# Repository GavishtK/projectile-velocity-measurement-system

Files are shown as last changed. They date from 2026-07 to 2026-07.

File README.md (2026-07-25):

# Projectile Velocity Measurement System (PVMS)

> **Development of an IoT-Based Projectile Velocity Measurement System**







---

# 📖 Overview

The **Projectile Velocity Measurement System (PVMS)** is an embedded system designed to accurately measure projectile velocity using the **Optical Time-of-Flight (ToF)** principle.

The system employs two optical sensing gates connected to an **ESP32** microcontroller. As a projectile passes through the sensing gates, the ESP32 records the elapsed time with microsecond precision and calculates the projectile's velocity.

The measured velocity is displayed in real time on an OLED display and simultaneously transmitted through the Serial Monitor for debugging and data logging.

To improve hardware integration and reliability, a **custom PCB was designed using KiCad**, incorporating interfaces for the ESP32, OLED display, optical sensors, laser modules, and power connections.

This project was developed as part of a **summer internship at DRDO**. This repository contains only my original implementation, documentation, and hardware design intended for educational and portfolio purposes. No confidential or restricted information has been included.

---

# 📷 Project Preview

## Hardware Prototype

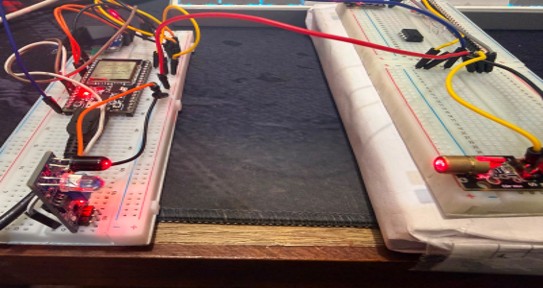
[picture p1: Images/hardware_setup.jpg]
Hardware Setup


## OLED Display

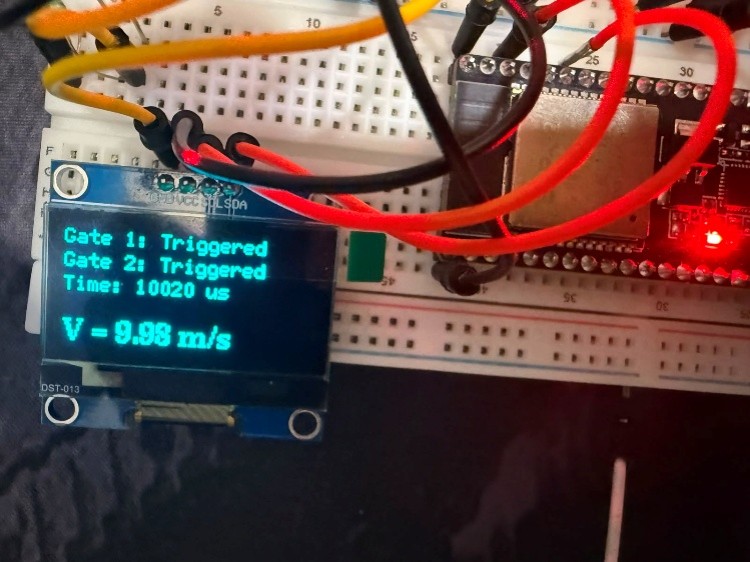
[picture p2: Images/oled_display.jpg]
OLED Display


## PCB Schematic

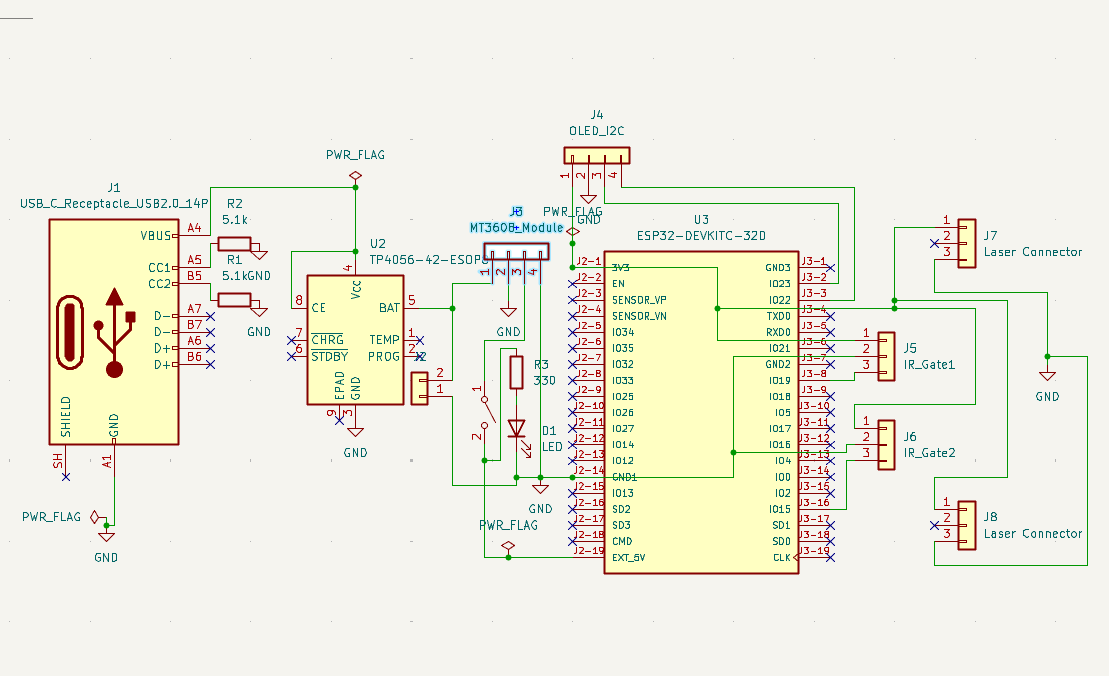
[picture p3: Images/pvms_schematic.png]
PCB Schematic


## PCB Layout

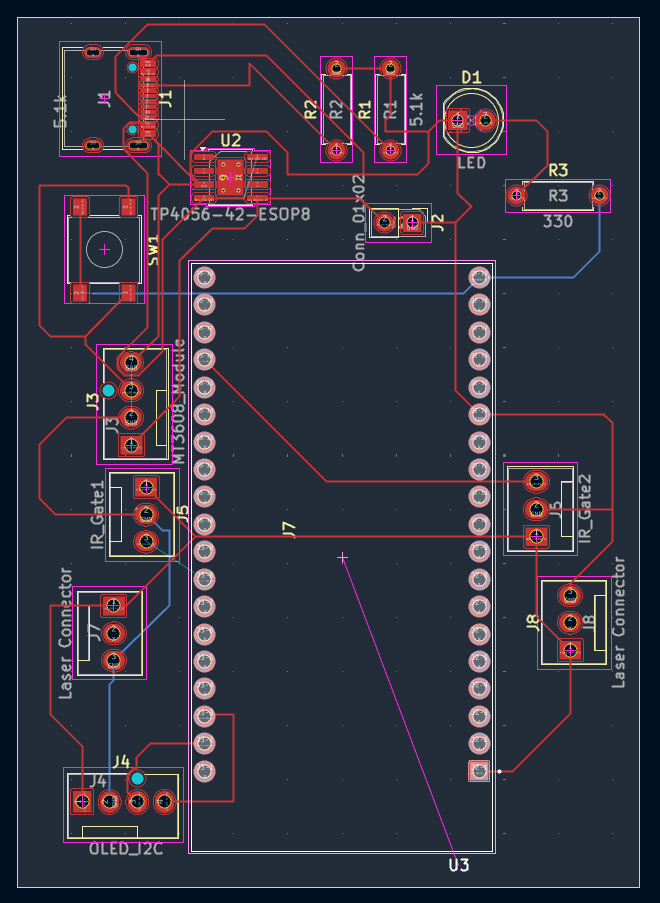
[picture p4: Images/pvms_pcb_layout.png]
PCB Layout


## PCB 3D Model

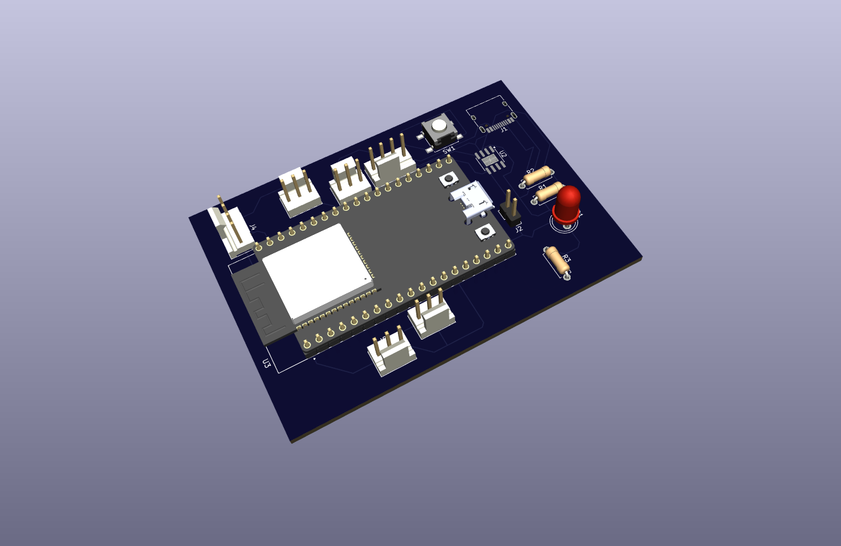
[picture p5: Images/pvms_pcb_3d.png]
PCB 3D Model


---

# ✨ Features

- High-speed projectile velocity measurement
- Optical Time-of-Flight sensing
- ESP32-based embedded system
- Microsecond precision using hardware interrupts
- Real-time OLED display
- Serial Monitor output
- Automatic timeout handling
- Low-cost implementation
- Custom KiCad PCB
- Compact and portable design

---

# ⚙ Hardware Used

| Component | Quantity |
|---|---|
| ESP32 DevKit V1 | 1 |
| SSD1306 OLED Display (128×64) | 1 |
| Laser Modules | 2 |
| Photodiodes | 2 |
| Breadboard | 1 |
| Jumper Wires | As Required |
| USB Power Supply | 1 |

---

# 🛠 Software Used

- Arduino IDE
- ESP32 Board Package
- KiCad
- Adafruit SSD1306 Library
- Adafruit GFX Library
- Wire Library

---

# 💻 PCB Design

A custom PCB was designed using **KiCad** to simplify wiring, improve reliability, and provide a compact hardware platform.

### PCB Features

- ESP32 interface
- OLED display connector
- Optical sensor connectors
- Laser module connectors
- Power input connector
- Compact PCB layout
- 3D STEP model included

---

# 🚀 Working Principle

The system consists of two optical sensing gates placed at a fixed distance.

1. The first optical gate detects the projectile.
2. ESP32 starts a high-resolution timer using hardware interrupts.
3. The second optical gate detects the projectile.
4. ESP32 stops the timer.
5. Velocity is calculated using the Time-of-Flight equation.

\[
Velocity = \frac{Distance}{Time}
\]

The calculated velocity is displayed on the OLED screen and transmitted through the Serial Monitor.

---

# 📋 Technical Specifications

| Parameter | Value |
|---|---|
| Controller | ESP32 DevKit V1 |
| Measurement Method | Optical Time-of-Flight |
| Timing Resolution | Microseconds |
| Display | SSD1306 OLED |
| PCB Software | KiCad |
| Firmware | Arduino C++ |

---

# 🧰 Skills Demonstrated

- Embedded Systems
- ESP32 Programming
- Arduino C++
- PCB Design (KiCad)
- Optical Sensor Interfacing
- Hardware Interrupt Programming
- Time-of-Flight Measurement
- Electronic Circuit Design
- Technical Documentation

---

# 📂 Repository Structure

```text
Projectile-Velocity-Measurement-System/
│
├── README.md
├── LICENSE
├── .gitignore
│
├── docs/
│   └── Final_Report.pdf
│
├── src/
│   └── ProjectileVelocityMeasurement.ino
│
├── Images/
│   ├── hardware_setup.jpg
│   ├── oled_display.jpg
│   ├── pvms_schematic.png
│   ├── pvms_pcb_layout.png
│   └── pvms_pcb_3d.png
│
└── pcb/
    ├── pvms.kicad_pro
    ├── pvms.kicad_sch
    ├── pvms.kicad_pcb
    └── pvms.step
```

---

# 📊 Results

The developed prototype successfully measured projectile velocity using optical sensing gates with stable and repeatable measurements.

The system demonstrated:

- Reliable optical triggering
- Accurate microsecond timing
- Stable velocity calculations
- Real-time OLED display
- Successful custom PCB design and 3D model generation

---

# 🔮 Future Improvements

- Rechargeable battery system
- Wireless data logging
- Mobile application
- Cloud connectivity
- 3D-printed enclosure
- Automatic calibration system

---

# 👨‍💻 Author

**Gavisht Karkara**

B.Tech Electronics & Communication Engineering

Thapar Institute of Engineering and Technology

---

# 📜 License

This project is licensed under the MIT License.

---

# ⚠ Disclaimer

This project was developed as part of a summer internship at **DRDO**.

This repository contains only my own implementation, firmware, PCB design, and documentation intended for educational and portfolio purposes. No confidential, proprietary, or restricted information has been included.

## ⭐ If you found this project useful, consider giving it a star!

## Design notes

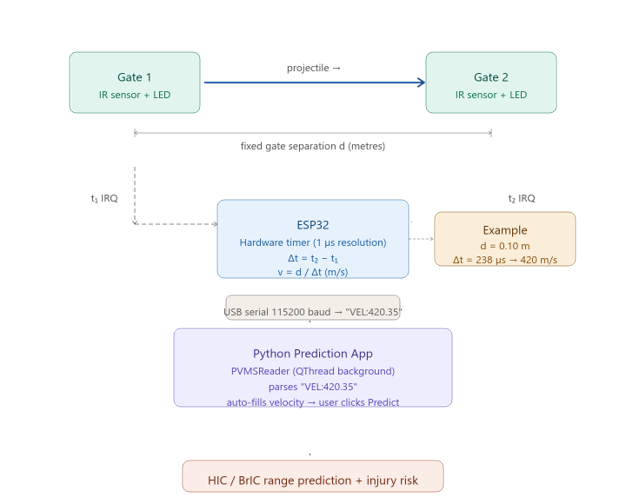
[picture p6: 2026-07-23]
Images/block_diagram.png

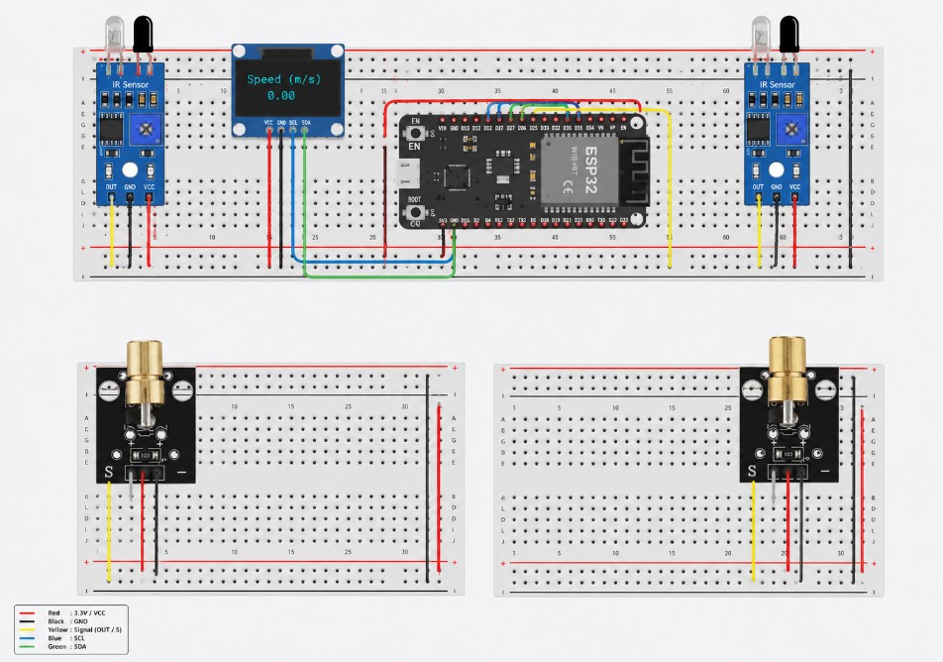
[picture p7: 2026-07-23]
Images/tinkercad.png

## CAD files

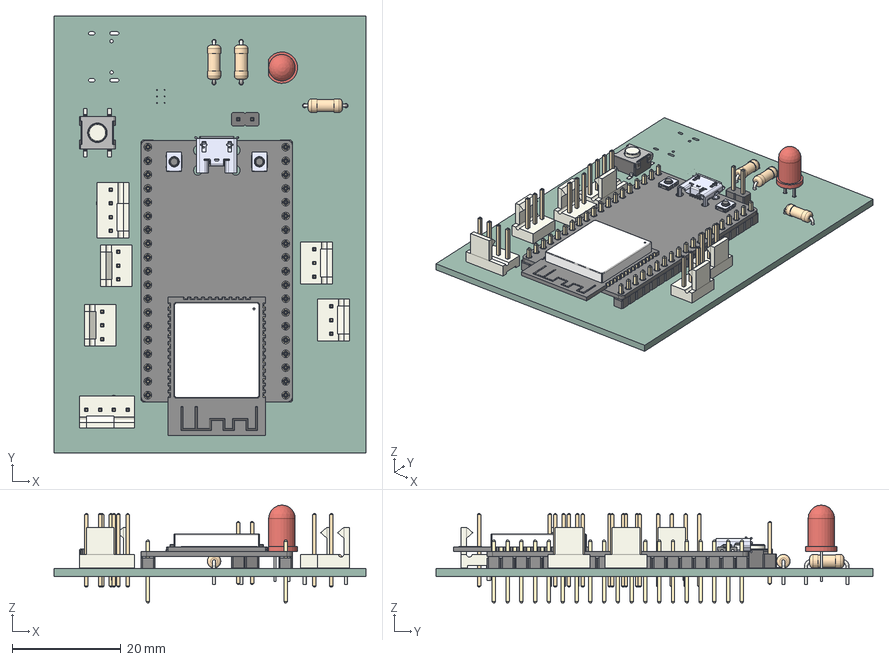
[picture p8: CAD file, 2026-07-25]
pcb/pvms.step
57.5 x 80.5 x 18.0 mm
R_Axial_DIN0207_L63mm_D25mm_P762mm_Horizontal x 3
LED_D5.0mm
SW_SPST_B3S-1000
Fan_Pin_Header_Straight_1x03 x 4
PinHeader_1x02_P254mm_Vertical
Fan_Pin_Header_Straight_1x04 x 2
board
header x 2
ESP32-WROOM-32D
micro usb
button x 2
pvm389E_PCB

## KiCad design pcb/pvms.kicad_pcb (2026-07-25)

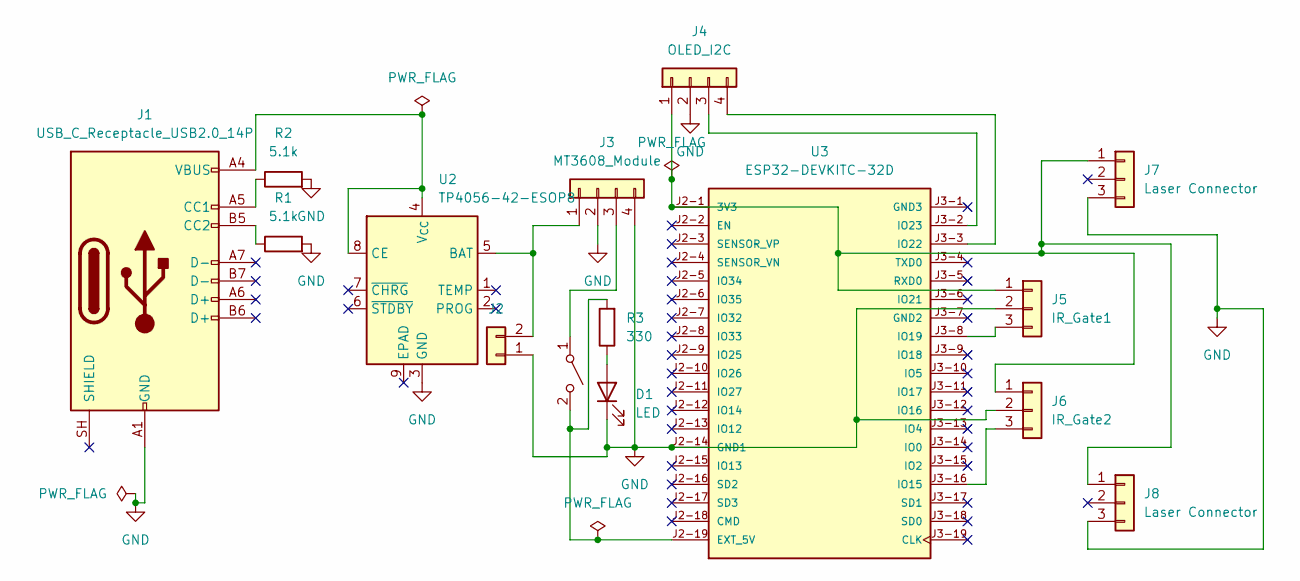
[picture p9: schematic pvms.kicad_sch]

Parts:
D1: LED; LED_D5.0mm
J1: USB_C_Receptacle_USB2.0_14P; USB_C_Receptacle_HRO_TYPE-C-31-M-12
J2: Conn_01x02; PinHeader_1x02_P2.54mm_Vertical
J3: MT3608_Module; FanPinHeader_1x04_P2.54mm_Vertical
J4: OLED_I2C; FanPinHeader_1x04_P2.54mm_Vertical
J5: IR_Gate1; FanPinHeader_1x03_P2.54mm_Vertical
J6: IR_Gate2; FanPinHeader_1x03_P2.54mm_Vertical
J7, J8: Laser Connector; FanPinHeader_1x03_P2.54mm_Vertical
R1, R2: 5.1k; R_Axial_DIN0207_L6.3mm_D2.5mm_P7.62mm_Horizontal
R3: 330; R_Axial_DIN0207_L6.3mm_D2.5mm_P7.62mm_Horizontal
SW1: SW_SPST; SW_SPST_B3S-1000
U2: TP4056-42-ESOP8; SOIC-8-1EP_3.9x4.9mm_P1.27mm_EP2.41x3.3mm_ThermalVias
U3: ESP32-DEVKITC-32D; MODULE_ESP32-DEVKITC-32D; PARTREV V4

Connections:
GND: D1.1 (K), J1.A1 (GND), J1.A12 (GND), J1.B1 (GND), J1.B12 (GND), J2.1, J3.2, J3.4, J4.2, J5.2, J6.2, J7.3, J8.3, R1.2, R2.2, U2.3 (GND), U3.J2-14 (GND1)
unnamed: D1.2 (A), R3.1
unnamed: J1.A5 (CC1), R2.1
unnamed: J1.B5 (CC2), R1.1
unnamed: J2.2, J3.1, U2.5 (BAT)
unnamed: J3.3, SW1.1 (A)
unnamed: J4.1, J5.1, J6.1, J7.1, J8.1, U3.J2-1 (3V3)
unnamed: J4.3, U3.J3-2 (IO23)
unnamed: J4.4, U3.J3-3 (IO22)
unnamed: J5.3, U3.J3-8 (IO19)
unnamed: J6.3, U3.J3-16 (IO15)
unnamed: R3.2, SW1.2 (B), U3.J2-19 (EXT_5V)
unnamed: J1.A4 (VBUS), J1.A9 (VBUS), J1.B4 (VBUS), J1.B9 (VBUS), U2.4 (V_{CC}), U2.8 (CE)

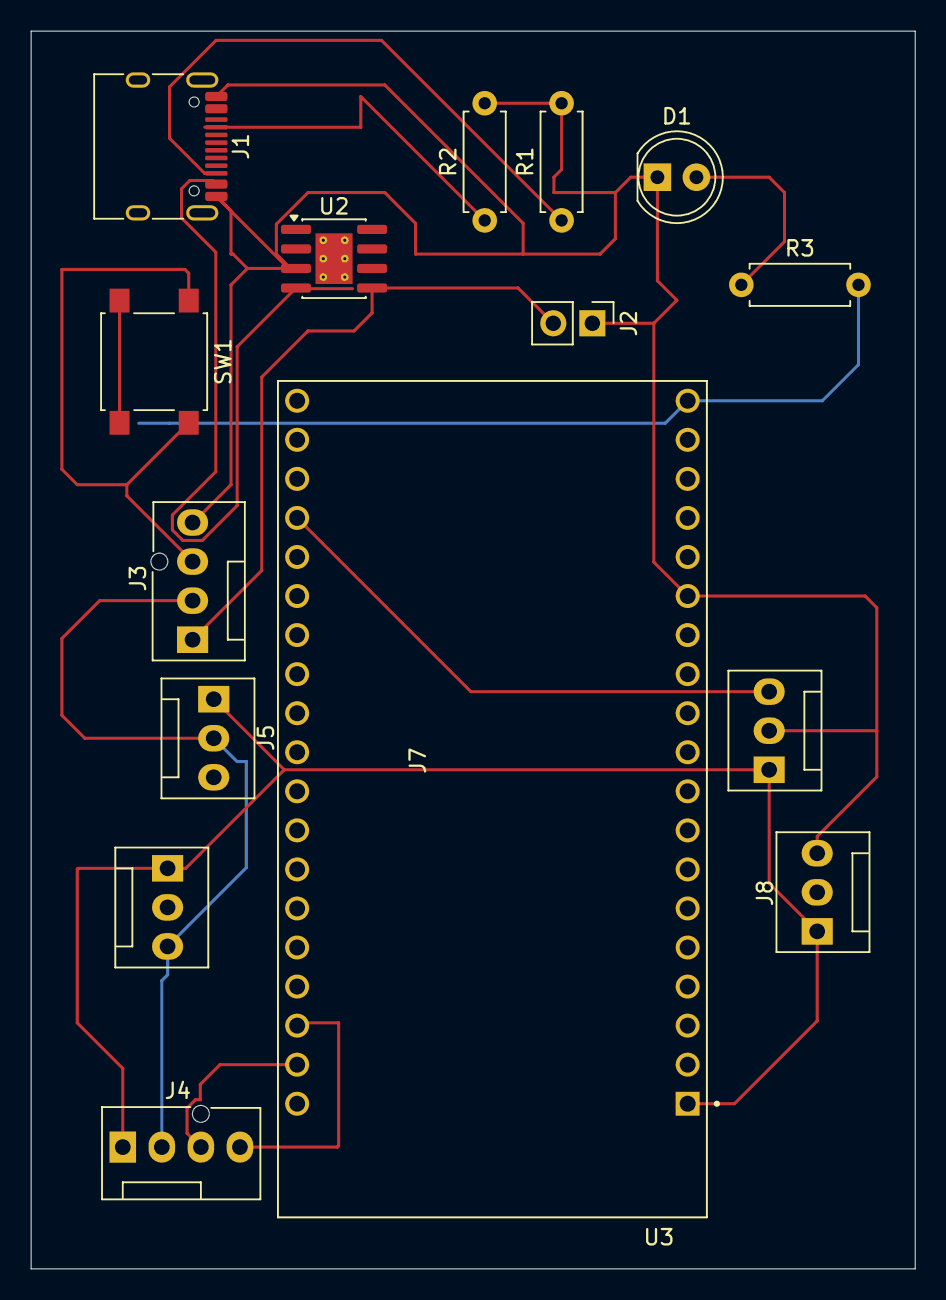
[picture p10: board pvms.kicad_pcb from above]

Board: 2 copper layers, 57.5 x 80.5 mm, 15 parts (0 on the bottom side), 13 nets.

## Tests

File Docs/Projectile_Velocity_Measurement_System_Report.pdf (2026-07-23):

## Abstract

The ballistics helmet test produces massive amounts of sensor data which needs to be analyzed in order to

assess biomechanical injury metrics including HIC36 and BrIC. However, the conventional method of analysis

via the use of commercial software such as NI DIAdem is slow, expensive in terms of licensing fees, and lacks

predictive ability.

The current project entails the development of a desktop application using the Python language for automating

the biomechanical analysis process. The desktop application is developed using the PytS framework and it

imports CSV and Excel files with sensor data (raw or filtered, computes the HIC36 and BrIC, finds the peak

value of all twelve sensor channels, and shows the results in seven pairs of graphs. Another aspect of the

current project included research into the Hybrid III head-neck assembly with the sensors installed on it.

In order to enhance the accuracy of the results generated by the Python software package, the generated results

were compared against NI DIAdem with regard to the data acquired from nine ballistic tests. The corrections

were made in the following manner, with a factor of 1.40 for HIC and 0.57 for BrIC being derived.

The software also incorporates a machine learning model for prediction that includes algorithms such as

random forest, linear regression, and gradient boosting in order to predict the HIC and BrIC with respect to

the speed of the projectile, projectile type, helmet type, and side of impact.

Other features included in the program are a graphical impact side selector, velocity versus drop height map,

and injury severities.

In addition, a compact Prototype of a Projectile Velocity Measurement System (PVMS) was developed using

a breadboard in order to obtain projectile velocities. These velocities were compared to the known reference

values of the velocities obtained from the existing system and the percentage error was computed in order to

test the accuracy of the prototype. The sofiware also contains an impact side selection window, a drop height

to velocity look-up table and injury severity categorization based on biomechanical standards.

The entire system can be summarized to provide an efficient platform for automated biomechanical analysis,

velocity measurements, and injury predictions without expending much manual effort and still agreeing well

with standard reference techniques.

## Table of content

## Chapter 1 - Introduction

### 1.1 Project Background

With the rising need for better personal protection in defense and law enforcement, ballistse helmets have come to be a vital part of protective gear. The key purpose of wearing such helmets is not just protection from penetration by projectiles, but also reduction in the transmission of impact forces to the wearer's head. Even if the projectile is stopped, the force that will be transmitted can be enough to cause TBI

Traumatic Brain Injury (TBI) refers to an injury caused by the action of an external mechanical force on the brain. TBI is divided into two types; that is, penetrating TBI, which involves a foreign body entering the brain, and non-penetrating or blunt TBI, involving rapid movement of the brain within the skull as a result of impact forces. In testing for helmet performance, the non-penetrating TBI is more of a problem since it could happen even if the helmet protects the head from projectile

penetration.

For the purpose of analyzing the efficiency of the ballistic helmet in resisting injuries caused by those mechanisms, a biomechanical test has to be conducted by means of an instrumented head form fitted with calibrated sensors. Data from the tests conducted on impact will be analyzed and injury criteria will be calculated; these criteria will be compared with safety levels.

### 1.2 Problem Definition

The current method of analyzing the collected data regarding the helmet impacts is based mainly on the use of commercially available software programs like NI DIAdem. This process involves manual loading of each individual CSV file, channel selection, filter setting, HIC and BrIC calculation, graph plotting, and writing of all these results down. All this has to be done for each separate test that makes this process quite lengthy and laborious. There is a high risk of errors when dealing with large number of tests performed on helmets using various ammunition types and different points of impact.

A third weakness of the present approach to the analysis is that there is no element of predictability within the system at all. The program only analyzes the results from tests carried out and cannot predict what the values of HIC or BrIC would be under various conditions of the speed of the projectile, the type of ammunition used, the type of helmet used, and the point of contact between the projectile and the helmet. This is especially useful considering the costliness of ballistic testing.

Morcover, the current process is not integrated for the velocity measurement of projectiles in the testing process.The measurement of velocity is always done separately through a commercially available chronograph and the value is then manually input increases the likelihood of data entry errors.

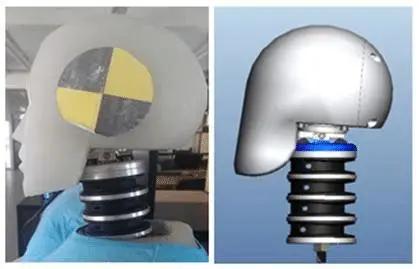
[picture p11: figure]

Figure 1: Head-Neck Assembly

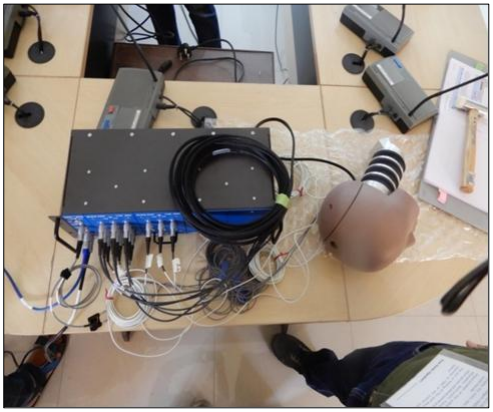
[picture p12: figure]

Figure 2: Head-Neck Assembly Setup

### 1.3 Understanding the Hybrid Ill Head-Neck Assembly

Hybrid III 50th percentile male Anthropomorphic Test Device (ATD) is one of the most commonly employed dummy types for assessment of occupant restraints and protection devices. It was initially designed by General Motors and is presently supported by Humanetics in partnership with SAE International and NHTSA. Hybrid III ATD is listed in the United States Code of Federal Regulations (Part 572, Subpart E), and it is intended to reflect the dimensions of a typical adult male body.

The head module comprises a metal skull made from aluminum and coated with vinyl to mimic the shape of the human head. The neck module has alternating aluminum disks and rubber inserts that mimic the stiffness and damping characteristics of the human neck. This makes it possible for the headform to behave in response to the loads applied in a manner that is comparable to the way the human body behaves, thus allowing the recorded sensor information to be compared against known injury criteria for humans.

The sensors are placed on the head form at points that correspond to the centre of gravity of the human head. The linear accelerometers placed at this point sense acceleration in three mutually perpendicular directions. Angular rate sensors sense rotation around the three mutually perpendicular axes. The neck load cell is a six-axis sensor that measures force and moments transferred across the cervical spine of the human body.

### 1.4 Project Objectives

The main goals of the project include the following:

- Performing research on Hybrid III head-neck subsystem and getting familiar with the sensors employed by the system and their properties, including operating principle, channel number, measurement range, and unit of measurement.
- Creating a desktop application implemented with Python programming language, able to open the raw and filtered CSV/Excel data files, calculate the HIC36 and BrIC indicators, show peak values for all twelve sensor channels, and plot time-history graphs in pairs.
- Checking the differences between HIC and BrIC calculated by Python and NI DIAdem software, determining appropriate correction coefficients, and applying them to improve the accuracy of calculations.
- Implementing a machine learning prediction model which would be able to estimate HIC and BrIC indicators basing on parameters such as projectile velocity, ammunition type, helmet type, and impact side using a database of real experimental data and physics-generated data.
- Creating an intuitive interface that would contain a graphical head diagram for choosing the side of the impact, and a drop height table for easier input of velocities while making drop-test predictions.

## Chapter 2 - Review of Literature

### 2.1 Head Injury Criterion (HIC)

The Head Injury Criterion (HIC) was formulated based on the work by Versace (1971) from the Biomechanics Research Laboratory at Wayne State University. This criterion has been devised based on earlier studies on the tolerance of head trauma, where it was found to have a correlation between the amount and duration of head acceleration and chances of skull fracture. The HIC is currently one of the most accepted biomechanical injury criteria in use today.

HIC combines both the magnitude and duration of head acceleration into a single injury metric, making it a more reliable indicator of head injury risk than peak acceleration alone. The HIC36 criterion used in this project limits the maximum duration of the evaluation window to 36 milliseconds, in accordance with the SAE J211 and FMVSS 208 standards.

HIC is defined as the maximum value of the following expression over all possible time intervals [t₁, t₂]:

HIC = (t2 − t1

)((
1
t2 − t1

) ∫ a(t)dt

(t2

)

t1

)

2.5
( )

where a(t) represents the resultant head acceleration measured in g, while t₁ and t₂ denote the start and end of the selected time interval in seconds.

The exponent 2.5 is based on experimental studies which showed that the severity of head injury depends not only on acceleration but also on the duration for which it acts. As a result, sustained high acceleration produces a much greater injury risk than a short-duration impact. Consequently, even small variations in the acceleration signal can significantly influence the calculated HIC value, highlighting the importance of appropriate signal filtering before analysis.

Algorithm: Sliding Window Maximisation

The HIC value is determined using a brute-force sliding window algorithm applied to the filtered resultant acceleration signal within a ±20 ms interval around the peak acceleration. The computation is performed as follows:

- Select each sample within the impact window as the starting index (i).
- Extend the ending index (j) while ensuring that (t[j] − t[i]) ≤ 36 ms.
- Determine the average acceleration over the selected interval using trapezoidal numerical integration:

### avg =

### ∫ a dt (t₂ − t₁)

- Calculate the HIC value for that interval:

HIC candidate = (t₂ − t₁) × avg².5

- Repeat the process for all possible (i, j) combinations and record the maximum HIC value obtained.

At 50,000 Hz the impact window contains approximately 2,000 samples, making the O(n²) complexity practical for processing an individual test file.

Table 1: HIC Risk Classification

HIC Range | Risk Level | Standard Reference
0 – 250 | Safe | EN 397 drop test safe limit
250 – 1000 | Moderate | NIJ 0106.01 ballistic pass/fail threshold
1000 – 2400 | Severe | FMVSS 208 severe injury region
> 2400 | Critical | FMVSS 208 fatal injury threshold

### 2.2 Brain Injury Criterion (BrIC)

Takhounts et al. (2013) proposed Brain Injury Criterion (BrIC) to address the drawback of HIC, since HIC only accounts for translational acceleration but ignores brain injury due to rotational acceleration. An important mechanism of injury because of rotational acceleration is Diffuse Axonal Injury (DAI). DAI happens when the brain moves rotationally within the skull, stretching and shearing the white matter axons. This injury may lead to unconsciousness, cognitive dysfunction, and, in severe cases, brain injury or even death.

BrIC is defined as:
BrIC = √(
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
where:

- ωx, ωy, ωz are the peak angular velocities about the X (Roll), Y (Pitch), and Z (Yaw) axes, respectively, measured in rad/s.
- WXC, WYC, and WZC represent the critical angular velocity constants corresponding to a 50% probability of AIS 4+ brain injury. These constants were established by Takhounts et al. using reconstructed accident data and finite element head model simulations.
The critical angular velocity constants used are:
- WXC = 66.25 rad/s (Roll – highest tolerance)
- WYC = 56.45 rad/s (Pitch)
- WZC = 42.87 rad/s (Yaw – lowest tolerance and the most critical axis)

Algorithm: Peak Detection on Resultant Time Series

Unlike HIC, BrIC does not require a sliding window. The algorithm is:

- Convert from deg/s to rad/s: ωrad = ωdeg ×

π
180
- Compute BrIC at every sample: BrIC(t) = √(
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
- The peak BrIC is obtained by selecting the maximum BrIC value over the entire duration of the test.

Table 2: BrIC Risk Classification

BrIC Range | Risk Level | Description
0 – 0.20 | Safe | No brain injury expected
0.20 – 0.45 | Low | Minor rotational stress
0.45 – 0.65 | Moderate | Moderate DAI risk
0.65 – 0.80 | Severe | Severe DAI probable
> 0.80 | Critical | Catastrophic brain injury

### 2.3 Helmet Testing Standards

Three standards are relevant to this project:

- NIJ 0106.01 (National Institute of Justice, USA): This is the primary standard used for the certification of ballistic helmets. It specifies that the HIC value must not exceed 1000 during the acceptance testing procedure. Based on the level of protection offered against different ammunition types, helmets are classified into protection levels ranging from Level I to Level IIIA.
- EN 397 (European Standard for Industrial Safety Helmets): This standard applies to the performance evaluation of industrial safety helmets under drop-test conditions. Owing to the comparatively lower impact energies involved, the acceptable HIC limit is 250, which is considerably lower than that specified for ballistic helmet testing.
- IS 4151 (Bureau of Indian Standards): This Indian standard specifies the requirements for protective helmets and serves as the national reference for the procurement and evaluation of helmets used by defence and paramilitary organisations.

### 2.4 Existing Tools and Research Gap

NI DIAdem is one of the most widely used commercial software tools for biomechanical analysis of helmet impact data. It provides built-in functions for calculating HIC and BrIC, configurable signal filtering options, graphical visualization, and automated report generation. Despite these capabilities, the software requires a commercial licence and cannot be readily deployed on systems without a licensed installation. Furthermore, it does not offer any facility for predicting injury metrics before conducting physical impact tests.

Another commonly used platform is MATLAB with the Signal Processing Toolbox, which is extensively employed for signal processing and biomechanical data analysis in research applications. Although MATLAB offers powerful computational and visualization features, its usage is also restricted by licensing requirements.

A review of the available literature indicates that there is no publicly available, licence-free Python-based application that integrates automated biomechanical analysis with machine learning-based injury prediction into a single platform. This identified research gap served as the motivation for developing the system presented in this project, which combines automated signal processing, injury metric computation, and predictive analysis within a unified application.

## Chapter 3 - Sensors and Experimental Setup

### 3.1 Overview of the Head-Neck Assembly

Impact testing of all helmets was performed using a Hybrid III 50th percentile male Anthropometric Test Device (ATD) head-neck assembly. The headform consists of an aluminum skull covered with vinyl skin, closely replicating the geometry and mechanical properties of a human head. The neck is constructed from aluminum and rubber discs designed to mimic human neck flexion and extension. Figure 3 shows the complete Hybrid III head-neck assembly, while Figure 4 illustrates the six-axis neck load cell mounting.

The assembly is equipped with three types of sensors: linear accelerometers, angular rate sensors, and a six-axis neck load cell. Linear accelerometers measure acceleration along three perpendicular axes, angular rate sensors capture rotational motion, and the load cell records forces and moments acting on the neck.

Sensor outputs are recorded using a data acquisition system at a sampling rate of 50,000 samples per second per channel. Each impact test generates a CSV file containing a 22-row metadata header, a time column, and 12 sensor data channels.

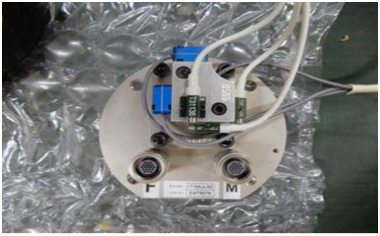
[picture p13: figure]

Figure 3: Load Cell - Six-Axial, Mounted on Headform

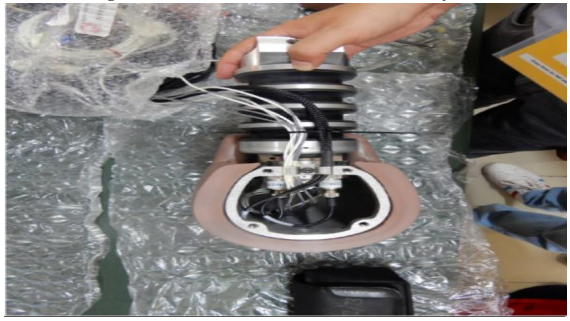
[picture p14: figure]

Figure 4: Load Cell Assembly – Middle View

Figure 4: Head and Neck Assembly - Exploded Views

### 3.2 Linear Acceleration Sensors (Endevco T-Series)

Three piezoresistive accelerometers, which provide measurement of translational acceleration along the X, Y, and Z axes, are installed in the Hybrid III headform. These instruments are attached to the centre of mass of the headform to register the translational acceleration produced during the collision. The working principle of piezoresistive accelerometers is based on the piezoresistive effect in which the seismic mass produces strain in silicon flexure beams with embedded piezoresistors.

The resistance of the piezoresistive sensors changes as a result of the accelerating force acting on the sensor in proportion to the loading force. This change in resistance is measured by a Wheatstone bridge circuit, and as a result, an output voltage is produced which is directly proportional to the acceleration.

Table 3: Linear Accelerometer Channel Assignments

Channel | Sensor ID | Axis | Unit | Range
Chan 0 | T31542 | X (fore-aft) | g | ±2000 g
Chan 1 | T32923 | Y (lateral) | g | ±2000 g
Chan 2 | T31139 | Z (vertical) | g | ±2000 g

Personal Observation
During my study on the sensor layout, I noticed that for successful detection of linear acceleration, it is necessary to arrange each uniaxial accelerometer properly inside the headform.

Table 4: Endevco 7268C Accelerometer Specifications

Parameter | 7268C-2000 (Value)

7268C-500
(Value)

Source

Measurement Range | ±2000 g | ±500 g | Endevco Datasheet 083019
Typical Sensitivity (10V excitation) | 0.20 mV/g (typ) | 0.80 mV/g (typ) | Endevco Datasheet 083019
Minimum Sensitivity | 0.15 mV/g (min) | 0.50 mV/g (min) | Endevco Datasheet 083019
Frequency Response (Z- axis) | 0 – 3,000 Hz (±5%) | 0 – 3,000 Hz (±5%) | Endevco Datasheet 083019

Frequency Response (X,Y
axes)

0 – 1,500 Hz
(±5%)

0 – 1,500 Hz
(±5%)

Endevco Datasheet 083019

Mounted Resonance Freq.
(Z)
26,000 Hz | 17,000 Hz | Endevco Datasheet 083019
Damping Ratio | 0.05 of critical | 0.05 of critical | Endevco Datasheet 083019
Non-linearity + Hysteresis | ±1% FSO | ±1% FSO | Endevco Datasheet 083019
Shock Survival (half-sine) | 10,000 g (200 µs) | 5,000 g (300 µs) | Endevco Datasheet 083019
Transverse Sensitivity | <3% max | <3% max | Endevco Datasheet 083019
Zero Measurand Output | ±100 mV max | ±100 mV max | Endevco Datasheet 083019
Excitation Voltage | 5 or 10 Vdc | 5 or 10 Vdc | Endevco Datasheet 083019
Weight (sensor only) | 8 g | 8 g | Endevco Datasheet 083019
Dimensions | 12.7 × 10.7 × 13.7 mm | 12.7 × 10.7 × 13.7 mm | Endevco PR Release, 2010
Operating Temperature | –18°C to +66°C | –18°C to +66°C | Endevco Datasheet 083019
Calibration Traceability | NIST traceable | NIST traceable | Endevco Datasheet 083019

Datasheet: Endevco 7268C specifications obtained from the official Endevco datasheet.

### 3.3 Angular Rate Sensors (ARS)

Three uniaxial ARSs are used for measuring the angular rotation about the X (roll), Y (pitch), and Z (yaw) axes. The ARSs work based on the Coriolis principle, which states that the vibration component of the sensor experiences a force acting perpendicular to the vibration as well as the rotating axis. This Coriolis force is directly proportional to the angular velocity of the input, thus resulting in an output voltage that is proportional to the rotational speed in deg/s.

The channel assignments, sensor IDs, measurement axes, and output units of the angular rate sensors used during testing are listed in Table 5.

Table 5: Angular Rate Sensor Channel Assignments

Channel | Sensor ID | Axis | Unit
Chan 3 | ARS21556 | X - Roll | deg/s
Chan 4 | ARS15978 | Y - Pitch | deg/s
Chan 5 | ARS21564 | Z - Yaw | deg/s

The orientation of the roll (X), pitch (Y), and yaw (Z) axes with respect to the headform is illustrated in Figure 6. Understanding this axis convention is essential for correctly interpreting the angular velocity measurements used in BrIC computation.

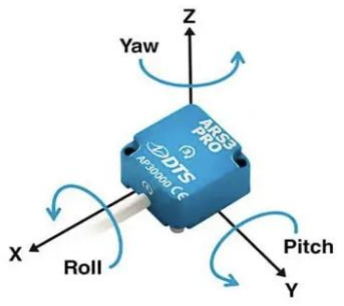
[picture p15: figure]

Figure 5: Angular Velocity - Sensor Axis Convention

Since the BrIC calculation requires angular velocity in radians per second (rad/s), the measured values must first be converted from degrees per second (deg/s) using:

ωrad = ωdeg ×

π
180

During the initial implementation, this conversion was unintentionally omitted, which resulted in BrIC values approximately 57 times higher than the correct values. The issue was later identified and corrected with the guidance of the project mentor.

The detailed specifications of the DTS ARS3 PRO sensors used in this study are summarized in Table 6.

Table 6: DTS ARS3 PRO Angular Rate Sensor Specifications

Parameter | ARS3 PRO-1500 Value

ARS3 PRO-8K
Value

Source

Range | ±1,500 deg/sec | ±8,000 deg/sec | DTS Datasheet DSH- 019, Rev. 12.2017
Bandwidth (standard) | 0–2,000 Hz | 0–2,000 Hz | DTS Datasheet DSH- 019, Rev. 12.2017
Noise (rated BW) | <0.15% FSO | <0.30% FSO | DTS Datasheet DSH- 019, Rev. 12.2017
Non-Linearity | <0.5% full scale | <0.5% full scale | DTS Datasheet DSH- 019, Rev. 12.2017
Cross-Axis Sensitivity | <1.0% | <1.0% | DTS Datasheet DSH- 019, Rev. 12.2017
Shock Survival | 10,000 g, 0.5 ms | 10,000 g, 0.5 ms | DTS Datasheet DSH- 019, Rev. 12.2017
IP Rating | IP67 | IP67 | DTS Datasheet DSH- 019, Rev. 12.2017
Excitation Voltage | 5.0–14.0 Vdc | 5.0–14.0 Vdc | DTS Datasheet DSH- 019, Rev. 12.2017
Full Scale Output | ±2 V nominal | ±2 V nominal | DTS Datasheet DSH- 019, Rev. 12.2017
Weight | 10 g (0.35 oz) | 10 g (0.35 oz) | DTS Datasheet DSH- 019, Rev. 12.2017
Dimensions | 19 × 19 × 12.5 mm | 19 × 19 × 12.5 mm | DTS Datasheet DSH- 019, Rev. 12.2017
Operating Temp. | −40 to +85°C | −40 to +85°C | DTS Datasheet DSH- 019, Rev. 12.2017
Calibration | NIST traceable; ISO 17025 A2LA accredited | NIST traceable; ISO 17025 A2LA accredited | DTS Datasheet DSH- 019, Rev. 12.2017

Datasheet: DTS ARS3 PRO specifications from the official datasheet DSH-019, Rev. 12.2017.

### 3.4 Six-Axis Neck Load Cell (Denton EW7402N)

The Denton EW7402N six-axis neck load cell is installed between the base of the skull and the upper cervical spine of the Hybrid III head-neck assembly. It measures three orthogonal force and three orthogonal moment components during impact.

The load cell uses strain gauges arranged in Wheatstone bridge circuits. Applied forces produce strain, causing a change in electrical resistance that is converted into voltage signals proportional to the measured forces and moments.

Figure 6: Load Cell - Six-Axial

Table 7: Load Cell – Six-Axial

Channel | Sensor ID | Measurement | Unit
Chan 6 | EW7402N-MX | Moment X | Nm
Chan 7 | EW7402N-MY | Moment Y | Nm
Chan 8 | EW7402N-MZ | Moment Z | Nm
Chan 9 | EW7402N-FX | Force X | N
Chan 10 | EW7402N-FY | Force Y | N
Chan 11 | EW7402N-FZ | Force Z | N

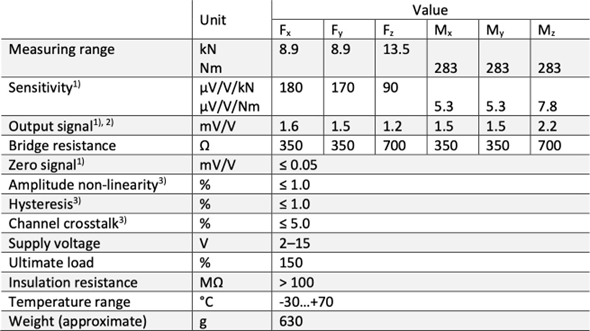
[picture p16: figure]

Figure 7: Six-Axis Neck Load Cell - Denton EW7402N
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

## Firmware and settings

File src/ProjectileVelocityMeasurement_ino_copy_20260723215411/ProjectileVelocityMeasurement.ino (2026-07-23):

/*
 * ==============================================================
 * Projectile Velocity Measurement System
 * --------------------------------------------------------------
 * Author   : Gavisht Karkara
 * Version  : v1.0
 * Year     : 2026
 *
 * Description:
 * Measures projectile velocity using two optical gates.
 * ESP32 records the travel time between Gate A and Gate B
 * with microsecond precision and displays the velocity on
 * an SH1106 OLED display.
 *
 * Formula:
 *      Velocity = Distance / Time
 *
 * Hardware:
 *  - ESP32 DevKit V1
 *  - SH1106 OLED Display (128x64)
 *  - Two Optical Gates
 *
 * ==============================================================
 */

#include <Wire.h>
#include <Adafruit_GFX.h>
#include <Adafruit_SH110X.h>

// =====================================================
// OLED
// =====================================================

Adafruit_SH1106G display(128, 64, &Wire, -1);

// =====================================================
// Pin Definitions
// =====================================================

constexpr uint8_t GATE_A_PIN = 18;
constexpr uint8_t GATE_B_PIN = 19;

constexpr uint8_t SDA_PIN = 21;
constexpr uint8_t SCL_PIN = 22;

// =====================================================
// Constants
// =====================================================

constexpr float GATE_DISTANCE_METERS = 0.15f;

constexpr unsigned long DISPLAY_TIME_MS = 5000;
constexpr unsigned long MIN_VALID_TIME_US = 100;
constexpr unsigned long MAX_VALID_TIME_US = 5000000;

// =====================================================
// Firmware Info
// =====================================================

const char* firmwareVersion = "v1.0";

// =====================================================
// Variables
// =====================================================

bool measurementInProgress = false;

unsigned long gateATime = 0;

int previousGateAState;
int previousGateBState;

// =====================================================
// Display Functions
// =====================================================

void showSplashScreen()
{
  display.clearDisplay();

  display.setTextSize(1);
  display.setCursor(5,10);
  display.println("Projectile Velocity");

  display.setCursor(25,25);
  display.println("Measurement");

  display.setCursor(45,40);
  display.println("System");

  display.setCursor(35,55);
  display.print("FW ");
  display.print(firmwareVersion);

  display.display();

  delay(2000);
}

void showReadyScreen()
{
  display.clearDisplay();

  display.setTextSize(1);

  display.setCursor(0,0);
  display.println("Projectile Velocity");

  display.setCursor(0,18);
  display.println("Status:");

  display.setCursor(55,18);
  display.println("READY");

  display.setCursor(0,40);
  display.println("Waiting for Gate A");

  display.display();
}

void showMeasuringScreen()
{
  display.clearDisplay();

  display.setTextSize(1);

  display.setCursor(0,0);
  display.println("Measurement Started");

  display.setCursor(0,25);
  display.println("Waiting for Gate B...");

  display.display();
}

void showVelocity(float velocity, unsigned long travelTime)
{
  display.clearDisplay();

  display.setTextSize(1);
  display.setCursor(0,0);
  display.println("Velocity");

  display.setTextSize(2);
  display.setCursor(0,18);
  display.print(velocity,1);
  display.print(" m/s");

  display.setTextSize(1);

  display.setCursor(0,46);
  display.print("Time : ");
  display.print(travelTime);
  display.print(" us");

  display.setCursor(0,56);
  display.print("Dist : 15 cm");

  display.display();
}

void showError(const char* message)
{
  display.clearDisplay();

  display.setTextSize(1);

  display.setCursor(0,0);
  display.println("ERROR");

  display.setCursor(0,20);
  display.println(message);

  display.display();

  delay(2000);
}

// =====================================================
// Setup
// =====================================================

void setup()
{
  Serial.begin(115200);

  pinMode(GATE_A_PIN, INPUT);
  pinMode(GATE_B_PIN, INPUT);

  Wire.begin(SDA_PIN, SCL_PIN);

  display.begin(0x3C, true);

  previousGateAState = digitalRead(GATE_A_PIN);
  previousGateBState = digitalRead(GATE_B_PIN);

  showSplashScreen();
  showReadyScreen();

  Serial.println();
  Serial.println("=====================================");
  Serial.println("Projectile Velocity Measurement");
  Serial.print("Firmware : ");
  Serial.println(firmwareVersion);
  Serial.println("System Ready");
  Serial.println("=====================================");
}

// =====================================================
// Main Loop
// =====================================================

void loop()
{
  int currentGateAState = digitalRead(GATE_A_PIN);
  int currentGateBState = digitalRead(GATE_B_PIN);

  // ---------------------------------------------------
  // Detect Gate A
  // ---------------------------------------------------

  if (!measurementInProgress &&
      currentGateAState != previousGateAState)
  {
    measurementInProgress = true;

    gateATime = micros();

    showMeasuringScreen();

    Serial.println();
    Serial.println("Gate A Triggered");
  }

  // ---------------------------------------------------
  // Detect Gate B
  // ---------------------------------------------------

  if (measurementInProgress &&
      currentGateBState != previousGateBState)
  {
    unsigned long gateBTime = micros();

    unsigned long travelTime = gateBTime - gateATime;

    if (travelTime < MIN_VALID_TIME_US)
    {
      showError("False Trigger");

      Serial.println("False Trigger");

      measurementInProgress = false;

      showReadyScreen();

      return;
    }

    if (travelTime > MAX_VALID_TIME_US)
    {
      showError("Timeout");

      Serial.println("Measurement Timeout");

      measurementInProgress = false;

      showReadyScreen();

      return;
    }

    float velocity =
      GATE_DISTANCE_METERS /
      (travelTime / 1000000.0f);

    // ---------------- Serial Output ----------------

    Serial.println("------------------------------");

    Serial.print("Travel Time : ");
    Serial.print(travelTime);
    Serial.println(" us");

    Serial.print("Velocity    : ");
    Serial.print(velocity,3);
    Serial.println(" m/s");

    Serial.println("------------------------------");

    showVelocity(velocity, travelTime);

    delay(DISPLAY_TIME_MS);

    measurementInProgress = false;

    showReadyScreen();
  }

  previousGateAState = currentGateAState;
  previousGateBState = currentGateBState;

  delay(1);
}

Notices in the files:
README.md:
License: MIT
